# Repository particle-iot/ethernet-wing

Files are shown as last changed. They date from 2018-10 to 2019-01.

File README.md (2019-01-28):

# ethernet-wing
*Hardware design files for the Particle Ethernet Wing*

The Ethernet FeatherWing is the fastest way to add wired connectivity to your Argon, Boron, or Xenon and turns any Particle Mesh developer kit into an Ethernet gateway. Based on the WIZnet W5500 chip, this side-by-side FeatherWing maintains great RF performance even while adding Ethernet connectivity to any Particle Mesh device.

The form-factor is based around the Adafruit FeatherWing Tripler. The two side connectors allow you to plug in one Particle Mesh device along with a Feather accessory.

- 10BaseT/100BaseTX Ethernet 
- Support Auto Negotiation (Full and half duplex, for both 10BaseT and 100BaseTX)

## Pin Map

|Mesh Pin|Ethernet FeatherWing Pin |
|:---|:---|
|MISO | SPI MISO |
|MOSI | SPI MOSI |
|SCK | SPI SCK |
|D3 | nRESET<sup>[1]</sup> |
|D4 | nINTERRUPT<sup>[1]</sup>  |
|D5 | nCHIP SELECT<sup>[1]</sup>|

**Notes:**

<sup>[1]</sup> These pins are connected via jumper pads on the bottom. You can cut these jumper traces and rewire them to a different pin on the Mesh device if the need arises. However the Device OS does not allow use of other pins (as of 0.8.0-rc.27).

The Ethernet driver for this wing is baked into the Mesh Device OS. When you set up a new Particle Mesh device that is plugged into an Ethernet FeatherWing, simply select the _USE WITH ETHERNET?_ option on your Particle mobile app and it should recognize and talk over Ethernet automagically. It's that simple.

## PoE (Power over Ethernet)

The PoE (Power over Ethernet) adapter for the Ethernet FeatherWing plugs into the Ethernet side of the FeatherWing. 

It uses the Silvertel Ag9905M and can supply 1800 mA to your device and any Feather accessories. It is a Class 0 IEEE 802.3af device.

| Parameter | Minimum | Typical | Maximum | Units |
| --- | --- | --- | --- | --- |
| Input Supply Voltage | 36 | 48 | 57 | Volts |
| Operating Temperature<sup>1</sup> | -40 | 25 | 70 | &deg;C |
| Output Voltage | | 5 | | V |
| Output Current | | | 1800 | mA |

<sup>1</sup>Operating temperature of the Ag9905M module only. The operating temperature range of the Xenon is smaller, -20 to +60&deg;C.

Note that because the Ethernet FeatherWing with PoE supplies 5V to the device by the VUSB pin, you should not power it by both PoE and the USB serial port at the same time.

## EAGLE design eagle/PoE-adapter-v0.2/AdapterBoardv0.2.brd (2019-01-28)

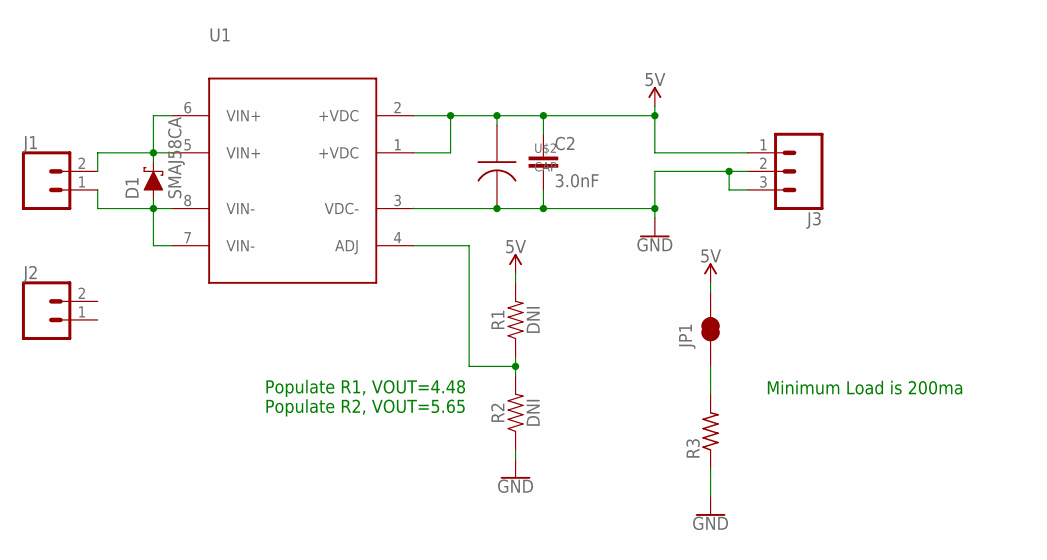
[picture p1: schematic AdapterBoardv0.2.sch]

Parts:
C2: 3.0nF; 0603
D1: SMAJ58CA; SMA-DIODE
J1, J2: CONN_02; 1X02
J3: CONN_03; 1X03
JP1: JUMPER-SMT_2_NC_TRACE_NO-SILK; SMT-JUMPER_2_NC_TRACE_NO-SILK
R1, R2: DNI; 0603
R3: R-US_R1210; R1210
U1: PARTICLE_AG9800AG99; AG9900
U$2: CAP

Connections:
5V: C2.1, J3.1, JP1.2, R1.2, U1.1 (+VDC), U1.2 (+VDC), U$2.A
ADJ: R1.1, R2.2, U1.4 (ADJ)
GND: C2.2, J3.2, J3.3, R2.1, R3.1, U1.3 (VDC-), U$2.C
unnamed: JP1.1, R3.2
V+: D1.C, J1.2, U1.5 (VIN+), U1.6 (VIN+)
V-: D1.A, J1.1, U1.7 (VIN-), U1.8 (VIN-)

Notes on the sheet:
Populate R1, VOUT=4.48 Populate R2, VOUT=5.65
Minimum Load is 200ma

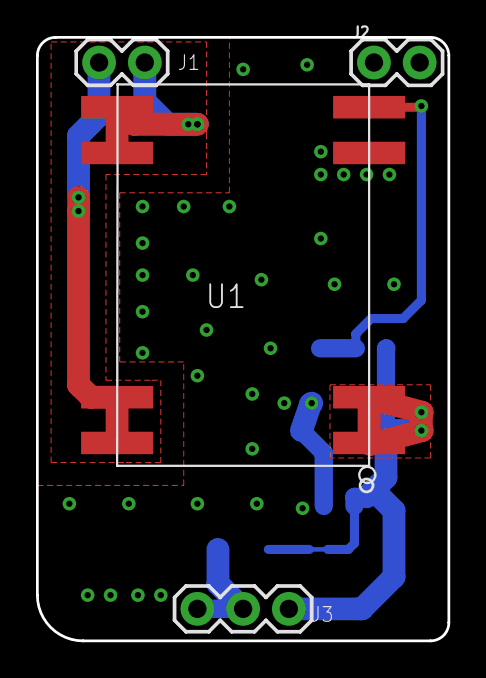
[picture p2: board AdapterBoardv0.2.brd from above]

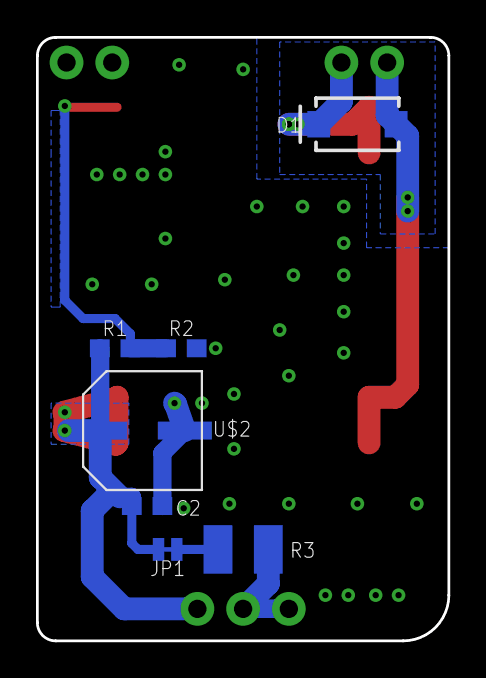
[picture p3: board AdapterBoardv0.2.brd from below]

Board: 2 copper layers, 22.9 x 33.5 mm, 11 parts (7 on the bottom side), 6 nets.

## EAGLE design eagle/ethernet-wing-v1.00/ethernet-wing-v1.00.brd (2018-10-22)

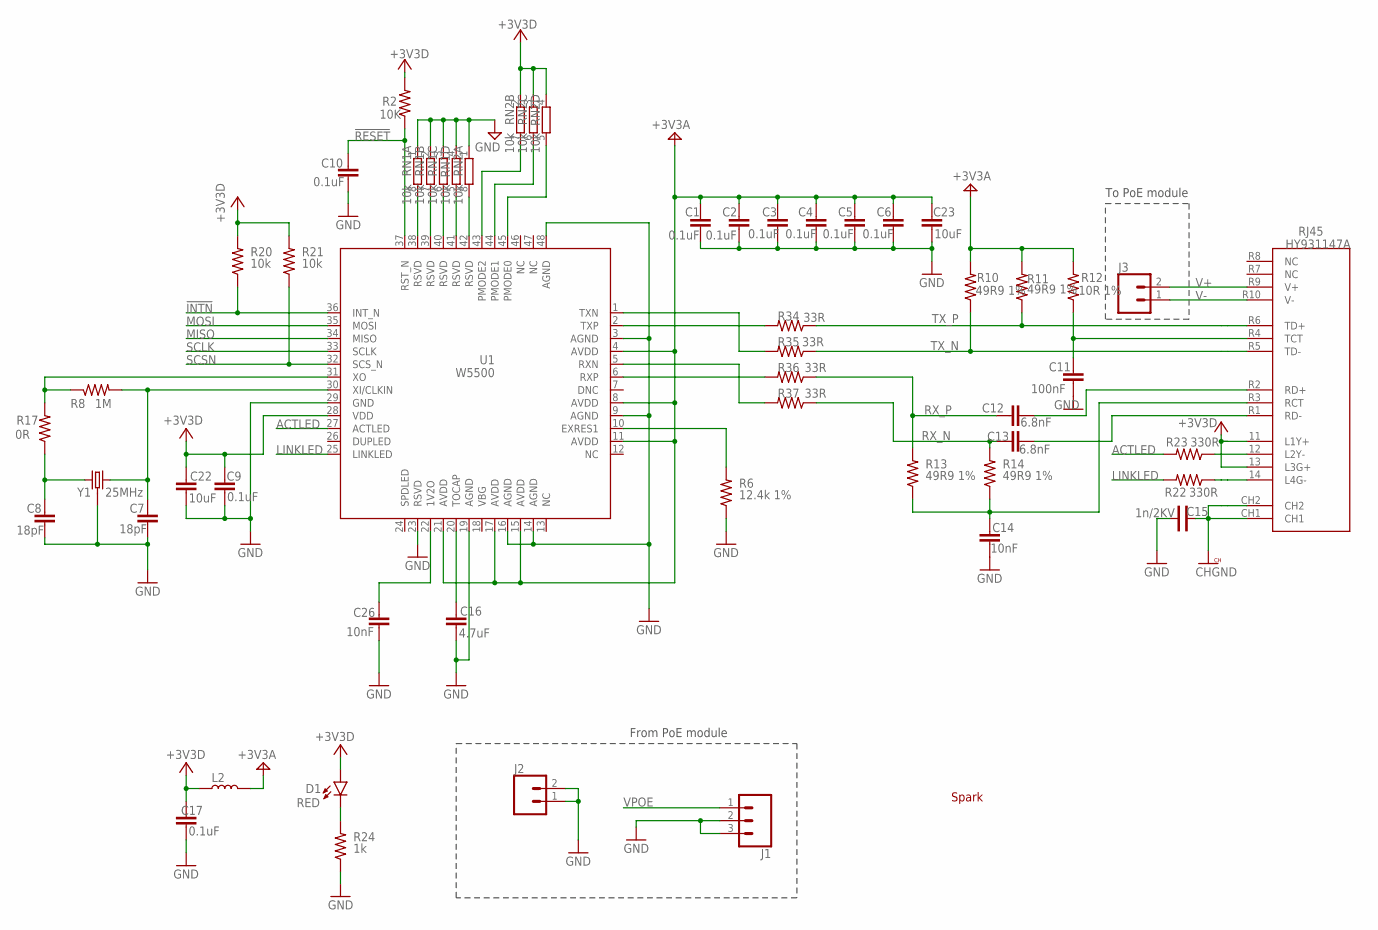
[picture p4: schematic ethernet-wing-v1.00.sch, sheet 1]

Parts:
C1, C2, C3, C4, C5, C6, C9, C10, C17: 0.1uF; C0402_B
C7, C8: 18pF; C0402_B
C11: 100nF; C0402_B
C12, C13: 6.8nF; C0402_B
C14, C26: 10nF; C0402_B
C15: 1n/2KV; C-1808
C16: 4.7uF; 0603
C22, C23: 10uF; 0603
D1: RED; LED-0603
J1: CONN_03; 1X03
J2, J3: CONN_02; 1X02
L2: INDUCTOR-0805-3.3UH; 0805
R2: 10K; R0402_B
R6: 12.4k 1%; R0402_B
R8: 1M; R0402_B
R10, R11, R13, R14: 49R9 1%; R0402_B
R12: 10R 1%; R0402_B
R17: 0R; R0402_B
R20, R21: 10k; R0402_B
R22, R23: 330R; R0402_B
R24: 1k; R0402_B
R34, R35, R36, R37: 33R; R0402_B
RJ45: HY931147A; ARDUINO-ETHERNET-SHIELD2-V2_CONNETTORI_POE-RJ45
RN1, RN2: 10k; 4X0402ARV341
U1: W5500
U$2: SPARK_LOGO2
Y1: 25MHz; CRYSTAL-SMD-3.2X2.5MM

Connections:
!INTN: R20.1, U1.36 (INT_N); also elsewhere on the board
!RESET: C10.2, R2.1, U1.37 (RST_N); also elsewhere on the board
+3V3: C9.2, C17.2, C22.1, D1.A, L2.1, R2.2, R20.2, R21.2, RJ45.11 (L1Y+), RJ45.13 (L3G+), RN2.2 (1), RN2.3 (1), RN2.4 (1), U1.28 (VDD); also elsewhere on the board
+3V3A: C1.2, C2.2, C3.2, C4.2, C5.2, C6.2, C23.1, L2.2, R10.2, R11.2, R12.2, U1.4 (AVDD), U1.8 (AVDD), U1.11 (AVDD), U1.15 (AVDD), U1.17 (AVDD), U1.21 (AVDD)
ACTLED: R23.2, U1.27 (ACTLED)
CHGND: C15.P$1, RJ45.CH1, RJ45.CH2
GND: C1.1, C2.1, C3.1, C4.1, C5.1, C6.1, C7.1, C8.1, C9.1, C10.1, C11.1, C14.1, C15.P$2, C16.2, C17.1, C22.2, C23.2, C26.1, J1.2, J1.3, J2.1, J2.2, R6.1, R24.1, RN1.1, RN1.2 (1), RN1.3 (1), RN1.4 (1), RN2.1, U1.3 (AGND), U1.9 (AGND), U1.14 (AGND), U1.16 (AGND), U1.19 (AGND), U1.23 (RSVD), U1.29 (GND), U1.48 (AGND), Y1.2 (3), Y1.4 (3); also elsewhere on the board
LINKLED: R22.2, U1.25 (LINKLED)
MISO: U1.34 (MISO); also elsewhere on the board
MOSI: U1.35 (MOSI); also elsewhere on the board
unnamed: RN2.7 (2), U1.43 (PMODE2)
unnamed: RN2.6 (2), U1.44 (PMODE1)
unnamed: RN2.5 (2), U1.45 (PMODE0)
unnamed: RN1.8 (2), U1.38 (RSVD)
unnamed: RN1.7 (2), U1.39 (RSVD)
unnamed: RN1.6 (2), U1.40 (RSVD)
unnamed: RN1.5 (2), U1.41 (RSVD)
unnamed: RN2.8 (2), U1.42 (RSVD)
unnamed: C8.2, R17.1, Y1.1
unnamed: C16.1, U1.20 (TOCAP)
unnamed: C26.2, U1.22 (1V2O)
unnamed: R6.2, U1.10 (EXRES1)
unnamed: C14.2, R13.1, R14.1, RJ45.R3 (RCT)
unnamed: D1.C, R24.2
unnamed: C11.2, R12.1, RJ45.R4 (TCT)
unnamed: R8.1, R17.2, U1.31 (XO)
unnamed: C7.2, R8.2, U1.30 (XI/CLKIN), Y1.3 (2)
unnamed: R23.1, RJ45.12 (L2Y-)
unnamed: R22.1, RJ45.14 (L4G-)
RR_N: C13.2, RJ45.R1 (RD-)
RR_P: C12.2, RJ45.R2 (RD+)
RX_N: C13.1, R14.2, R37.1
RX_P: C12.1, R13.2, R36.1
R_N: R37.2, U1.5 (RXN)
R_P: R36.2, U1.6 (RXP)
SCLK: U1.33 (SCLK); also elsewhere on the board
SCSN: R21.1, U1.32 (SCS_N); also elsewhere on the board
TX_N: R10.1, R35.1, RJ45.R5 (TD-)
TX_P: R11.1, R34.1, RJ45.R6 (TD+)
T_N: R35.2, U1.1 (TXN)
T_P: R34.2, U1.2 (TXP)
V+: J3.2, RJ45.R9 (V+)
V-: J3.1, RJ45.R10 (V-)
VPOE: J1.1; also elsewhere on the board

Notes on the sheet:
To PoE module
From PoE module

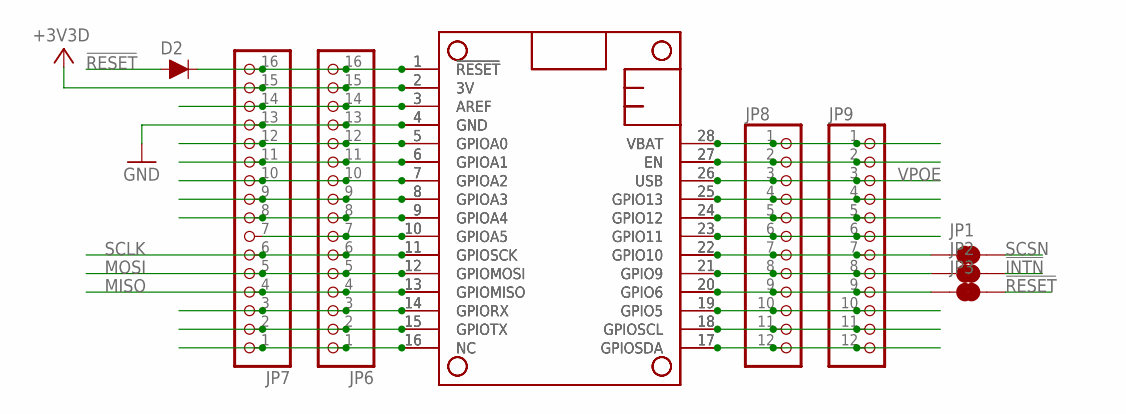
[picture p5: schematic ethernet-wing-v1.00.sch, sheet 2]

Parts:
D2: DIODE-BAS16J; SOD-323
JP1, JP2, JP3: JUMPER-SMT_2_NC_TRACE_NO-SILK; SMT-JUMPER_2_NC_TRACE_NO-SILK
JP6, JP7: MICROBUILDER_HEADER-1X16_76MIL; MICROBUILDER_1X16_ROUND_76MIL
JP8, JP9: MICROBUILDER_HEADER-1X1276MIL; MICROBUILDER_1X12_ROUND_76MIL
MS1, MS2: MICROBUILDER_FEATHERWING_NODIM; MICROBUILDER_FEATHERWING_DIM

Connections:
!INTN: JP2.2; also elsewhere on the board
!RESET: D2.A, JP3.2; also elsewhere on the board
!RESET!!: D2.C, JP6.16, JP7.16, MS1.1 (!RESET), MS2.1 (!RESET)
+3V3: JP6.15, JP7.15, MS1.2 (3V), MS2.2 (3V); also elsewhere on the board
GND: JP6.13, JP7.13, MS1.4 (GND), MS2.4 (GND); also elsewhere on the board
MISO: JP6.4, JP7.4, MS1.13 (GPIOMISO), MS2.13 (GPIOMISO); also elsewhere on the board
MOSI: JP6.5, JP7.5, MS1.12 (GPIOMOSI), MS2.12 (GPIOMOSI); also elsewhere on the board
unnamed: JP6.14, JP7.14, MS1.3 (AREF), MS2.3 (AREF)
unnamed: JP8.2, JP9.2, MS1.27 (EN), MS2.27 (EN)
unnamed: JP8.10, JP9.10, MS1.19 (GPIO5), MS2.19 (GPIO5)
unnamed: JP3.1, JP8.9, JP9.9, MS1.20 (GPIO6), MS2.20 (GPIO6)
unnamed: JP2.1, JP8.8, JP9.8, MS1.21 (GPIO9), MS2.21 (GPIO9)
unnamed: JP1.1, JP8.7, JP9.7, MS1.22 (GPIO10), MS2.22 (GPIO10)
unnamed: JP8.6, JP9.6, MS1.23 (GPIO11), MS2.23 (GPIO11)
unnamed: JP8.5, JP9.5, MS1.24 (GPIO12), MS2.24 (GPIO12)
unnamed: JP8.4, JP9.4, MS1.25 (GPIO13), MS2.25 (GPIO13)
unnamed: JP6.12, JP7.12, MS1.5 (GPIOA0), MS2.5 (GPIOA0)
unnamed: JP6.11, JP7.11, MS1.6 (GPIOA1), MS2.6 (GPIOA1)
unnamed: JP6.10, JP7.10, MS1.7 (GPIOA2), MS2.7 (GPIOA2)
unnamed: JP6.9, JP7.9, MS1.8 (GPIOA3), MS2.8 (GPIOA3)
unnamed: JP6.8, JP7.8, MS1.9 (GPIOA4), MS2.9 (GPIOA4)
unnamed: JP6.7, JP7.7, MS1.10 (GPIOA5), MS2.10 (GPIOA5)
unnamed: JP6.3, JP7.3, MS1.14 (GPIORX), MS2.14 (GPIORX)
unnamed: JP8.11, JP9.11, MS1.18 (GPIOSCL), MS2.18 (GPIOSCL)
unnamed: JP8.12, JP9.12, MS1.17 (GPIOSDA), MS2.17 (GPIOSDA)
unnamed: JP6.2, JP7.2, MS1.15 (GPIOTX), MS2.15 (GPIOTX)
unnamed: JP6.1, JP7.1, MS1.16 (NC), MS2.16 (NC)
SCLK: JP6.6, JP7.6, MS1.11 (GPIOSCK), MS2.11 (GPIOSCK); also elsewhere on the board
SCSN: JP1.2; also elsewhere on the board
VBAT: JP8.1, JP9.1, MS1.28 (VBAT), MS2.28 (VBAT)
VPOE: JP8.3, JP9.3, MS1.26 (USB), MS2.26 (USB); also elsewhere on the board

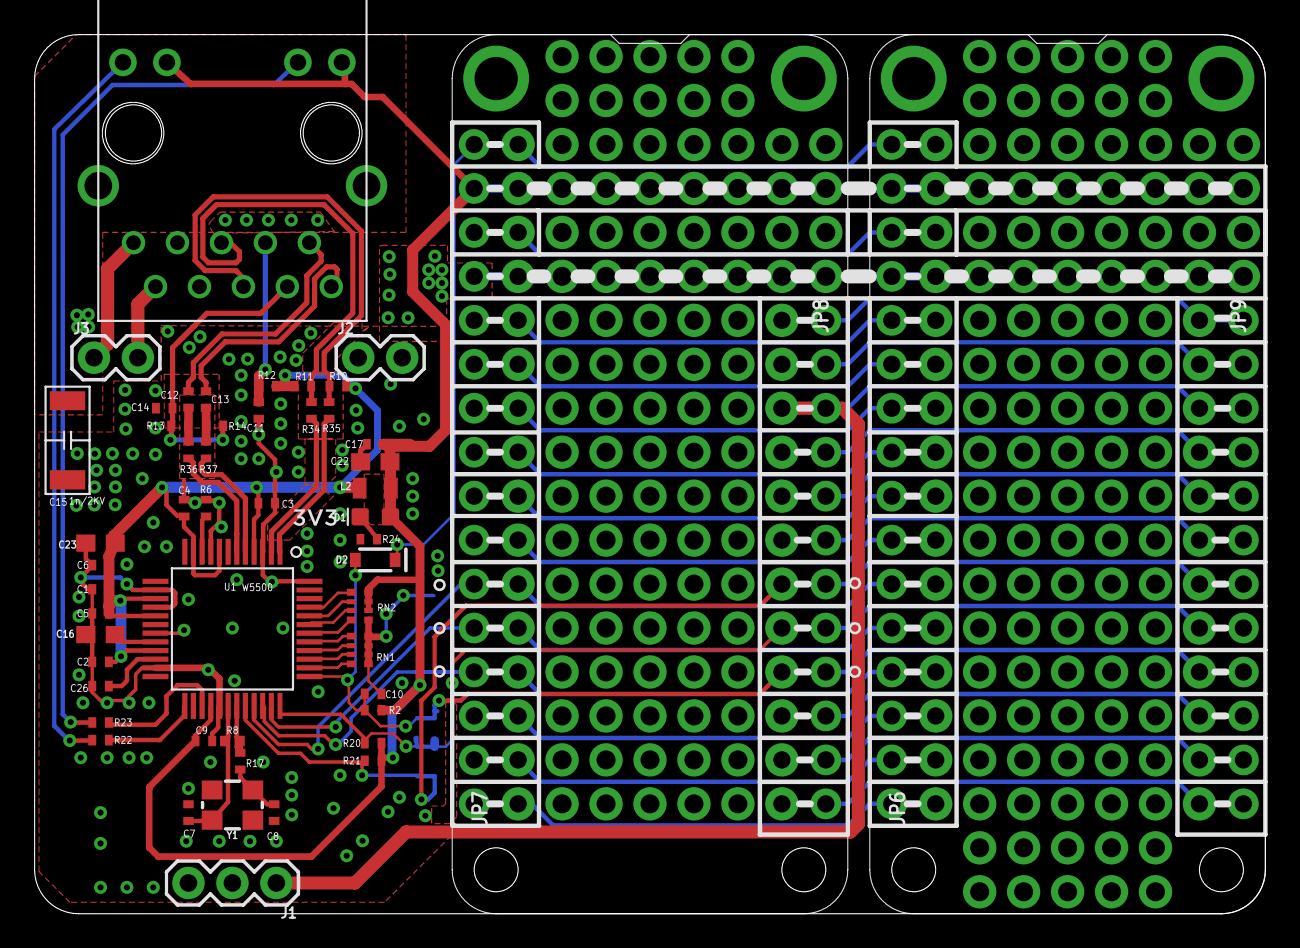
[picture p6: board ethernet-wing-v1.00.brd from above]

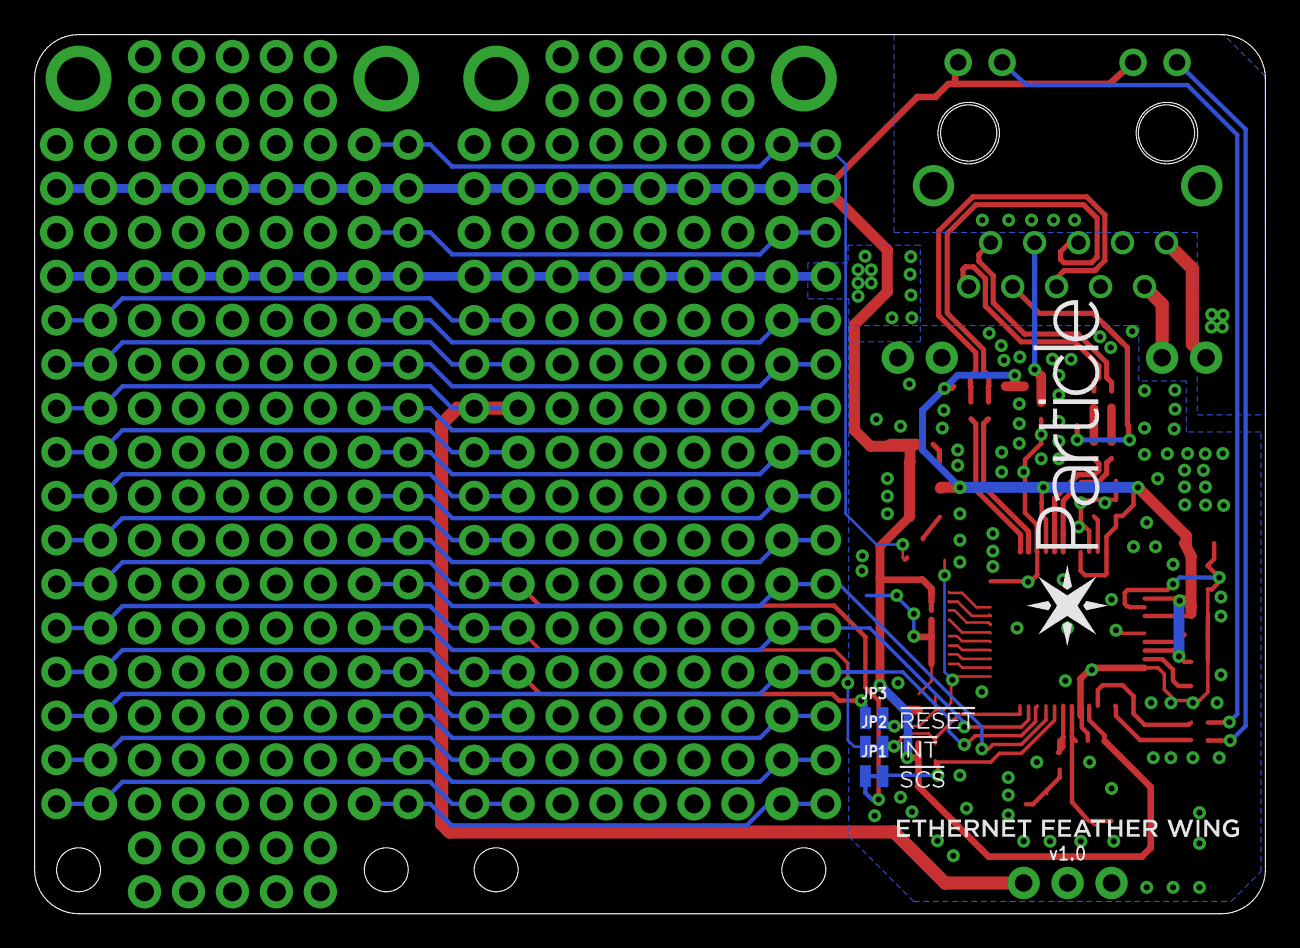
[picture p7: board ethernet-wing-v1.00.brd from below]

Board: 2 copper layers, 71.1 x 50.8 mm, 59 parts (3 on the bottom side), 66 nets.

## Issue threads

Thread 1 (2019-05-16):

Ethernet wing does not work well with SD Feather

jimmie11, 2019-05-16:
I am using Adafruit's SD Feather along with a Xenon and an Ethernet wing.  I changed the CS default to A0.

I keep having intermittent problems with the SD card not working.

Appears to be a conflict with SPI.  Please also refer to:

https://community.particle.io/t/xenon-sd-card-and-ethernet-not-working/48238/3

mdubiszj, 2019-07-19:
We also are trying to use the Ethernet Featherwing along with an [ADE9000](https://www.analog.com/en/products/ade9000.html#product-overview), but we cannot use them at the same time because the Featherwing uses up the SPI1 pins.

It would be helpful to be able to reconfigure which pins the Ethernet Feathewing uses.

orvisevans, 2019-11-19:
I believe you can reconfigure it by cutting the SCS trace on the bottom and soldering a jumper between the scs pad and whichever pin you'd like to use.
https://docs.particle.io/datasheets/accessories/mesh-accessories/#ethernet-featherwing

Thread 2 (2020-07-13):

BOM For Ethernet Wing

lauriaclarke, 2020-07-13:
Hello,

I have been using the ethernet feather wing for a COVID-19 project called VentMon.
https://www.pubinv.org/project/ventmon/

We are now spinning our own PCB and have used your design as a base. Would it be possible to get the BOM for this design? I'd be glad to share more of our work if you are interested.

Thanks!
Lauria

kennethlimcp, 2020-07-13:
@mohitbhoite @rickkas7

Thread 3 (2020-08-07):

Documentation, Libraries, Examples?

mrarmyant, 2020-08-07:
Trying to use this with Boron/Argon.  There are no libraries I can easily find outside of NCD's library which is a port of the original Arduino library.  It has the following error:

`lib/NCD_Ethernet_Overlay/Ethernet.h:71:8: reference to 'EthernetClass' is ambiguous
error
tcp_client.ino:20:15: 'class spark::EthernetClass' has no member named 'begin'`

Does Particle have any in house libraries or documentation for the w5500?

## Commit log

2018-10-22 added board design files
    [ethernet-wing-v1.00.brd, ethernet-wing-v1.00.sch]
2019-01-28 Add PoE adapter
    [AdapterBoardv0.2.brd, AdapterBoardv0.2.sch]

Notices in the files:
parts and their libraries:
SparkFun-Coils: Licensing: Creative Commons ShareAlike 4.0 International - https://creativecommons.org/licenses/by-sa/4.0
